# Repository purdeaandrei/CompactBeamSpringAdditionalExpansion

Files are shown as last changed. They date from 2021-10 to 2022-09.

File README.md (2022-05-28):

# Compact Beamspring controller.

This controller only supports new style card edge connectors only, and it requires the side
of the card edge connector to be cut off, and the pins be bent 90 degress.

This is a variant of the controller that also includes an additional expansion header, designed
especially for 3278 A02 / 3279 2C keyboards with a top panel, sporting additional leds and
non-capacitive push buttons.
See https://github.com/purdeaandrei/CompactBeamSpring/issues/1 for some details about these keyboards.

See [top_panel_modifications.md](top_panel_modifications.md) for instructions on how to connect this controller
to the top panel of your 3278 A02 / 3279 2C keyboard.

## Images

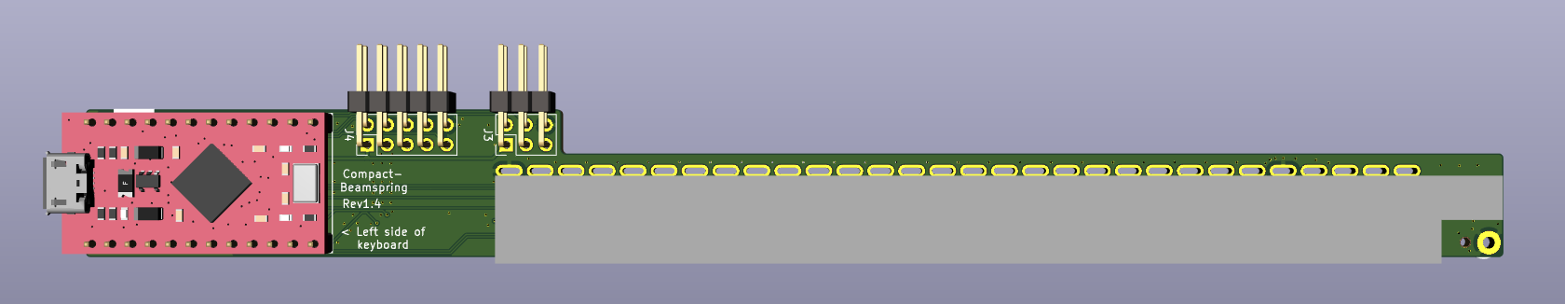
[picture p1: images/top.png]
Top of the controller board

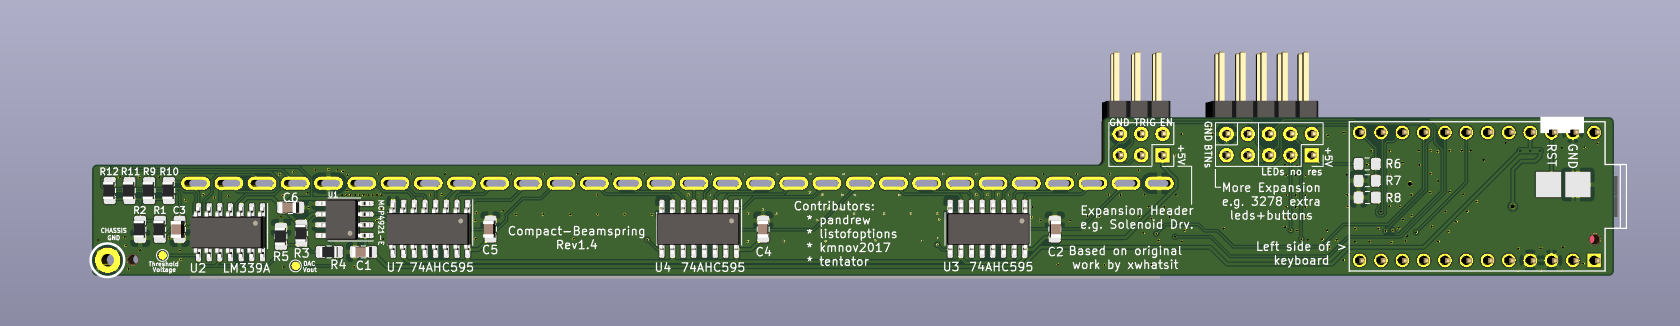
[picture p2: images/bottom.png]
Bottom of the controller board


## Other controllers in this family:
* https://github.com/purdeaandrei/CompactBeamSpring
* https://github.com/purdeaandrei/SMDModelFController
* https://github.com/purdeaandrei/SMDModelFController/tree/extra_columns
* https://github.com/purdeaandrei/SMD4704KishsaverClassModelFController
* https://github.com/listofoptions/TH-XWhatsIt

## Origins and license

This project is based on the Through-hole xwhatsit by listofoptions, which is un turn
based on the capsense controllers by XWhatsIt
(Tom Wong-Cornall). original liscencure holds, as well as CERN OSH
(compatible license).

original implementation of Tom Wong-Cornall's controller documented here

http://downloads.cornall.co/ibm-capsense-usb-web/ibm-capsense-usb.html

Working theory of operation is under the previous link.

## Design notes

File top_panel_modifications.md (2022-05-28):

# Top panel modifications

This document describes how to modify the top panel of the 3278 A02 / 3279 2C keyboard shown below:

## The top panel in its original state
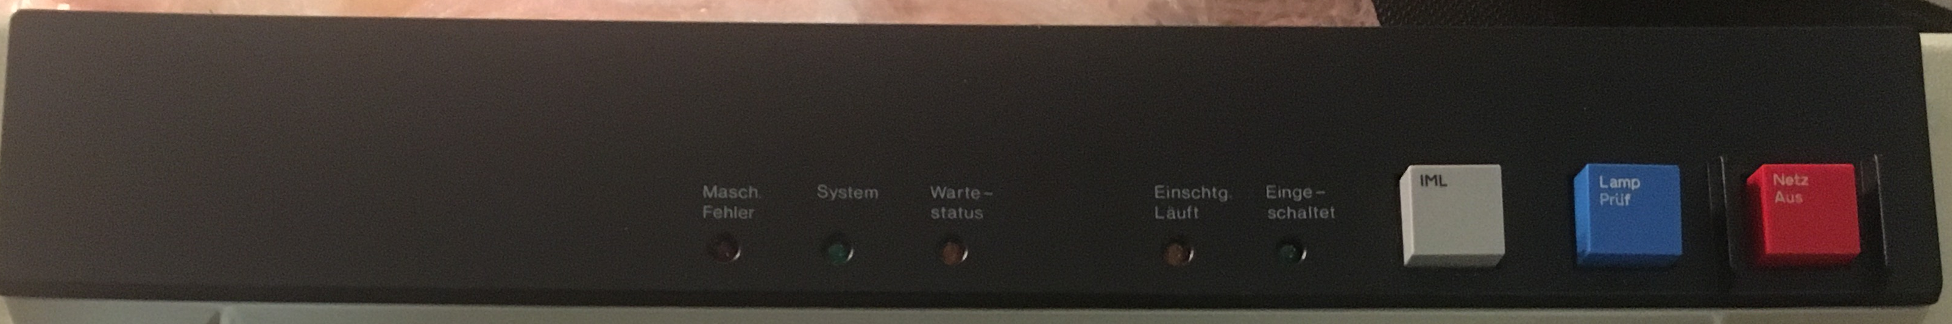
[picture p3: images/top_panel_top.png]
Top side of the top panel

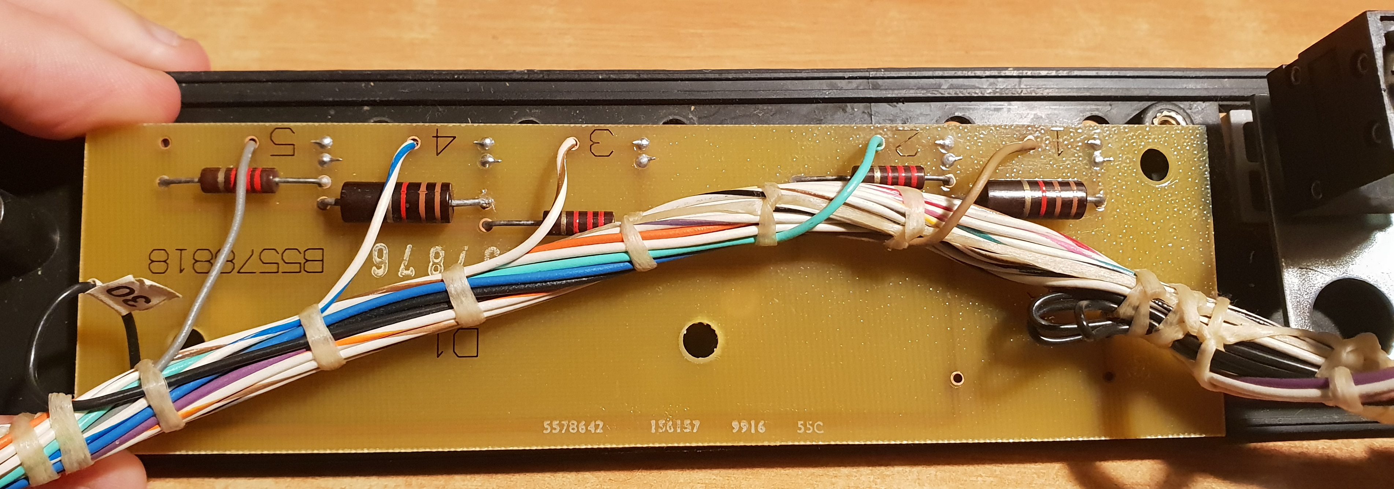
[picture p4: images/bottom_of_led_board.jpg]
Bottom side of the led pcb

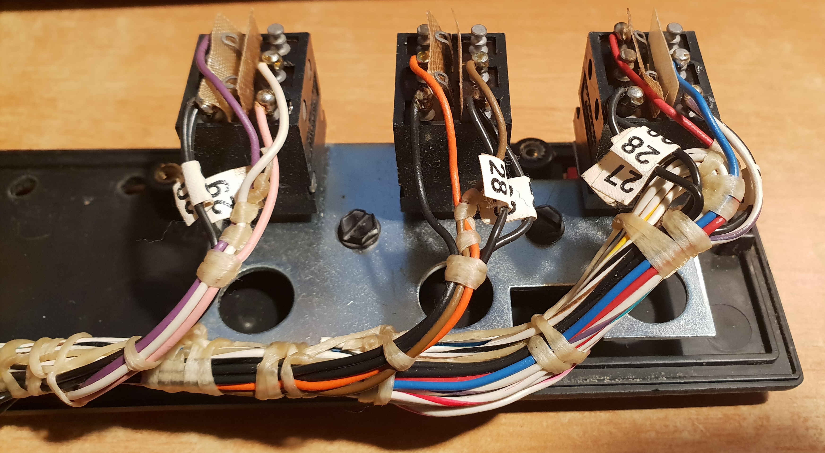
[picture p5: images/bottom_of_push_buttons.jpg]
Bottom side of the push buttons


Note: for more details about the original state of the board, please see [here](images/original_wire_harness_leds_and_buttons.pdf), and [here](images/bottom_of_push_buttons_annotated.jpg).

## After the modifications, the bottom side of the top panel looks like this:
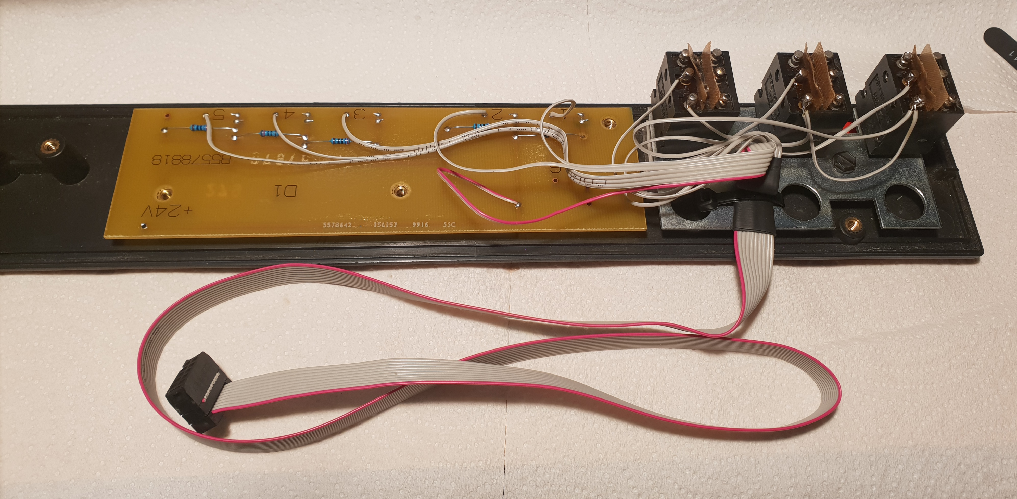
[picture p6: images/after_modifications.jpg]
After modifications


## Details

### Led Resistors

The original led board was designed to power the leds at 24 volts, so using the original current limiting resistors
at 5V, which is what our controller is running at, would make the leds too dim. In order to have the leds light at
a similar brightness as the original working condition of the keyboard, the resistors have to be replaced.

The following values have been calculated as recommended replacements. If you want to use these values
directly, please make sure that the board you're modifying had the same original resistor values as mentioned
in this table. Resistors are listed left-to-right:

| Led color | Index on PCB | Original resistor (@24V) | Recommended replacement (@5V) |
|---|---|---|---|
| Red | 5 | 2.2 kohm | 270 ohm |
| Green | 4 | 1.1 kohm | 120 ohm |
| Yellow | 3 | 2.2 kohm | 270 ohm |
| Yellow | 2 | 2.2 kohm | 270 ohm |
| Green | 1 | 1.1 kohm | 120 ohm |

Note: if you would like to see the raw spreadsheet we used to calculate the resistor values please see [here(.ods)](images/3278%20top%20panel%20led%20current%20limiting%20resistors.ods) or [here(.pdf)](images/3278%20top%20panel%20led%20current%20limiting%20resistors.pdf)

### New wire harness (using a ribbon cable)

#### Components

* 10-pin ribbon cable with 1.27mm pin pitch. We recommend using the single-color kind, that has only one edge wire with a different color. For example all-grey with pin "1" marked with red.
  * Example sources:
    * [tme](https://www.tme.eu/en/details/ds1057-10a282r/ribbon-cables-single-color/connfly/ds1057-10a282r-30-5/)
    * ebay, search "10 pin ribbon cable 1.27mm"
* 2x5-pin female IDC connector with 2.54mm pin pitch, and 1.27mm ribbon cable pitch:
  * Example sources:
    * [tme](https://www.tme.eu/en/details/ds1016-10masibb/idc-connectors/connfly/ds1016-10ma2bb/)
    * ebay, search "2x5 10 pin idc female"
* You also have the option to buy pre-crimped ribbon cables, and cut off one end, however you have less control over the length of the resulting cable harness.

Note: when crimping the IDC connector onto the ribbon cable, make sure to respect the pin 1 marker, which is usually a triangle/arrow showing which side pin 1 is on.

#### Wiring

| Ribbon pin index | Ribbon wire color | Controller net name | GPIO | Connect to |
|---|---|---|---|---|
| 1 | Red | +5VD | | "+24V" pin on led board, which is the **common anode** |
| 2 | Grey | LED1 | PF5  | "5" on PCB, The **left-most** led cathode |
| 3 | Grey | LED2 | PB4  | "4" on PCB, The second led cathode from the left |
| 4 | Grey | LED3 | PB5  | "3" on PCB |
| 5 | Grey | HEADER2_LED4 | PE6  | "2" on PCB |
| 6 | Grey | HEADER1_LED5 | PD7  | "1" on PCB, The **right-most** led cathode |
| 7 | Grey | BUTTON1 | PB6  | The **left-most** push buttons's middle-left terminal  |
| 8 | Grey | BUTTON2 | PB3  | The middle push buttons's middle-left terminal |
| 9 | Grey | BUTTON3 | PF4  | The **right-most** push buttons's middle-left terminal |
| 10 | Grey | GND | | The bottom-left pins of **all 3 push-buttons** |

Here is a futher illustrated image, explaining how to connecto the wires:

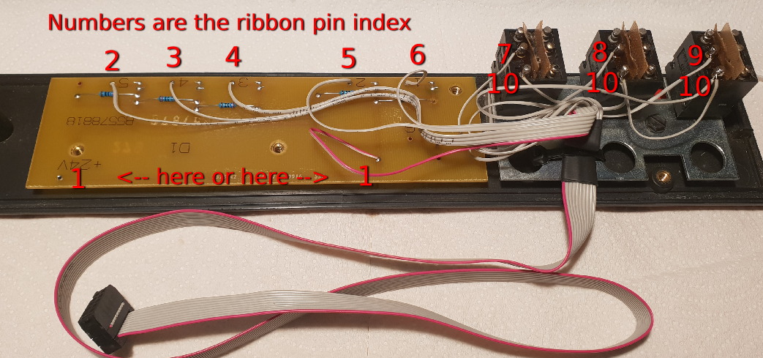
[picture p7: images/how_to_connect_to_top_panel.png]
How to connect


Here is an example of how to provide some strain relief to the ribbon cable using some heatshrink tubing, and a cable tie:

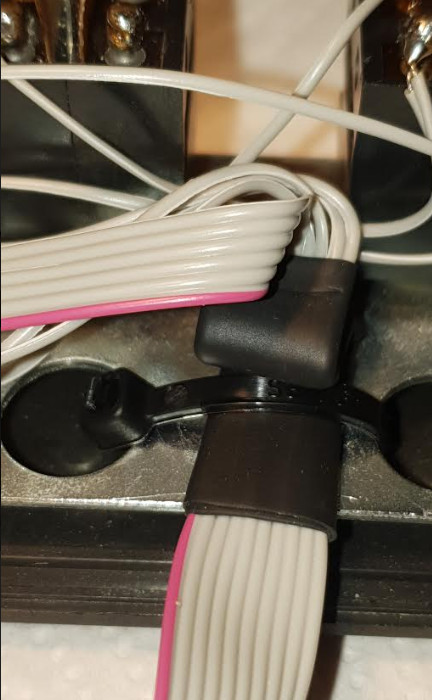
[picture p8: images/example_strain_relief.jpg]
Example strain relief


#### Connecting to the controller

Always make sure the pin "1" of the ribbon cable (the side marked with red) is lined up with pin "1" on controller.
Note: pin 1 on the controller is the only pad that is square, and it's also marked differently on the silkscreen.

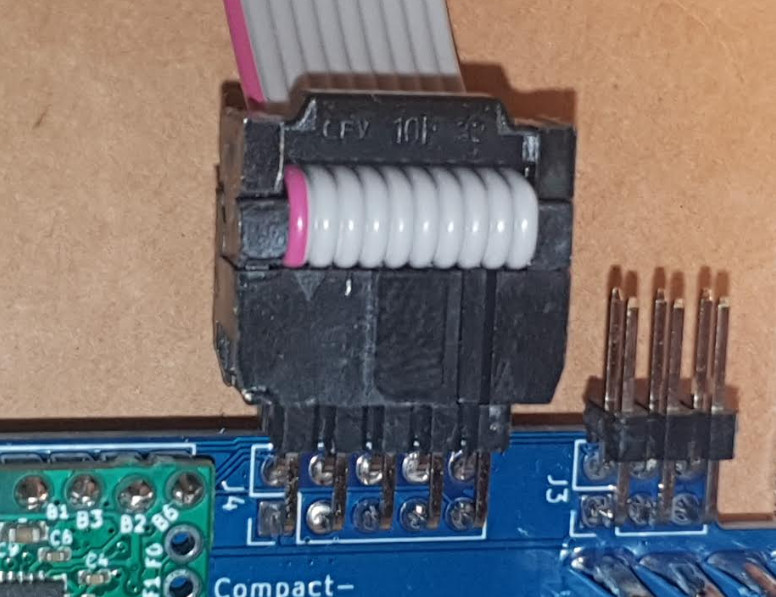
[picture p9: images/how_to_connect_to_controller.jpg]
How to connect


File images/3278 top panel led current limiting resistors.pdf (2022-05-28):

3278 A02 / 3279 2C keyboard top panel led behavour measured.

The original keyboard powered the led board at 24V.
The purpose of this table is to calculate the best replacement resistors to use at 5V, in order to closest approximate the original brightness of the leds.

Each led was powered, through its original current limiting resistor, at 23.9V with a lab power supply, and voltage drop and current were measured.

Right to Left: | Test voltage: | | 23.9 | V | | | Atmega VOL at measured current (V)
| Index on PCB | Current at 24V with original resistor | Original Resistance Measured | Resistance Color Code | Voltage on LED | -40degC | 25degC | 85degC | Total voltage available at 25degC | Voltage dropped by new resistor | New Resistor (ohms) | New resistor std value (ohms)
Green | 1 | 19.12 | mA | 1.122 | kohm | 1.1k | 2.19 | 0.55 | 0.68 | 0.9 | 4.32 | 2.13 | 111.4016736 | 120
Yellow | 2 | 9.4 | mA | 2.33 | kohm | 2.2k | 2.07 | 0.25 | 0.3 | 0.5 | 4.7 | 2.63 | 279.787234 | 270
Yellow | 3 | 9.17 | mA | 2.47 | kohm | 2.2k | 2.2 | 0.25 | 0.3 | 0.5 | 4.7 | 2.5 | 272.6281352 | 270
Green | 4 | 19.38 | mA | 1.116 | kohm | 1.1k | 2.07 | 0.55 | 0.68 | 0.9 | 4.32 | 2.25 | 116.0990712 | 120
Red | 5 | 9.48 | mA | 2.31 | kohm | 2.2k | 2.06 | 0.25 | 0.3 | 0.5 | 4.7 | 2.64 | 278.4810127 | 270

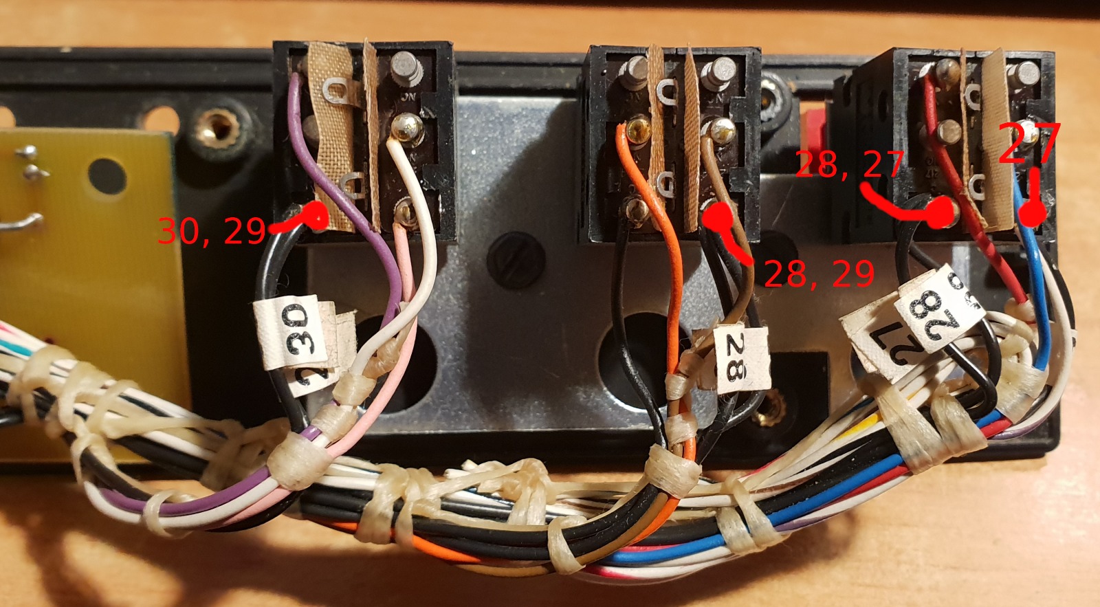
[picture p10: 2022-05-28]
images/bottom_of_push_buttons_annotated.jpg

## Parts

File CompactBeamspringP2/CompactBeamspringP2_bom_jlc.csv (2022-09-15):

Comment | Designator | Footprint | LCSC Part #
0U1 | C2,C6,C5,C3,C1,C4 | C_0805_2012Metric_Pad1.15x1.40mm_HandSolder | C49678
1K | R2 | R_0805_2012Metric_Pad1.15x1.40mm_HandSolder | C17513
20K | R4,R3 | R_0805_2012Metric_Pad1.15x1.40mm_HandSolder | C4328
4K7 | R5,R1 | R_0805_2012Metric_Pad1.15x1.40mm_HandSolder | C17673
100k 1% | R9,R10,R11,R12 | R_0805_2012Metric_Pad1.15x1.40mm_HandSolder | C149504
MCP4921-E | U1 | SOIC-8_3.9x4.9mm_P1.27mm | C43499
LM339A | U2 | SOIC-14_3.9x8.7mm_P1.27mm | C74559
74AHC595 | U3,U4,U7 | SOIC-16_3.9x9.9mm_P1.27mm | C5520

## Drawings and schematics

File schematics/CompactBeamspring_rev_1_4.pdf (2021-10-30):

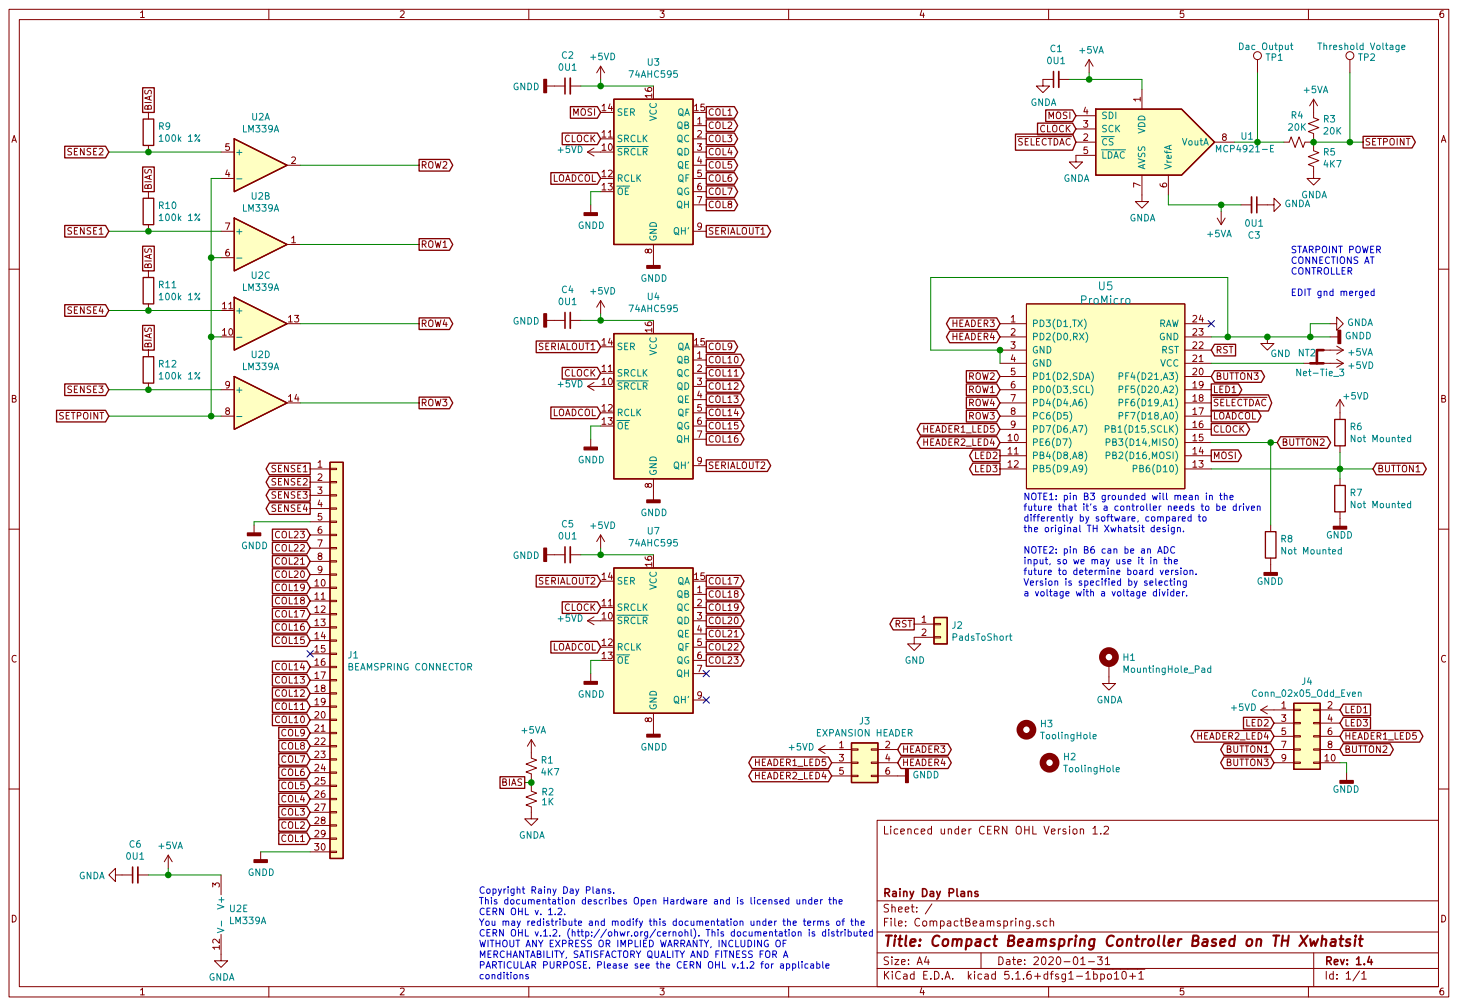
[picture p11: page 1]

future that it's a controller needs to be driven
differently by software, compared to
the original TH Xwhatsit design.

NOTE2: pin B6 can be an ADC
input, so we may use it in the
future to determine board version. Version is specified by selecting

a voltage with a voltage divider.

Licenced under CERN OHL Version 1.2

Copyright Rainy Day Plans.
This documentation describes Open Hardware and is licensed under the CERN OHL v. 1.2. You may redistribute and modify this documentation under the terms of the

File: CompactBeamspring.sch Sheet: / Rainy Day Plans

Id: 1/1 Title: Compact Beamspring Controller Based on TH Xwhatsit

CERN OHL v.1.2. (http://ohwr.org/cernohl). This documentation is distributed WITHOUT ANY EXPRESS OR IMPLIED WARRANTY, INCLUDING OF MERCHANTABILITY, SATISFACTORY QUALITY AND FITNESS FOR A

PARTICULAR PURPOSE. Please see the CERN OHL v.1.2 for applicable
conditions

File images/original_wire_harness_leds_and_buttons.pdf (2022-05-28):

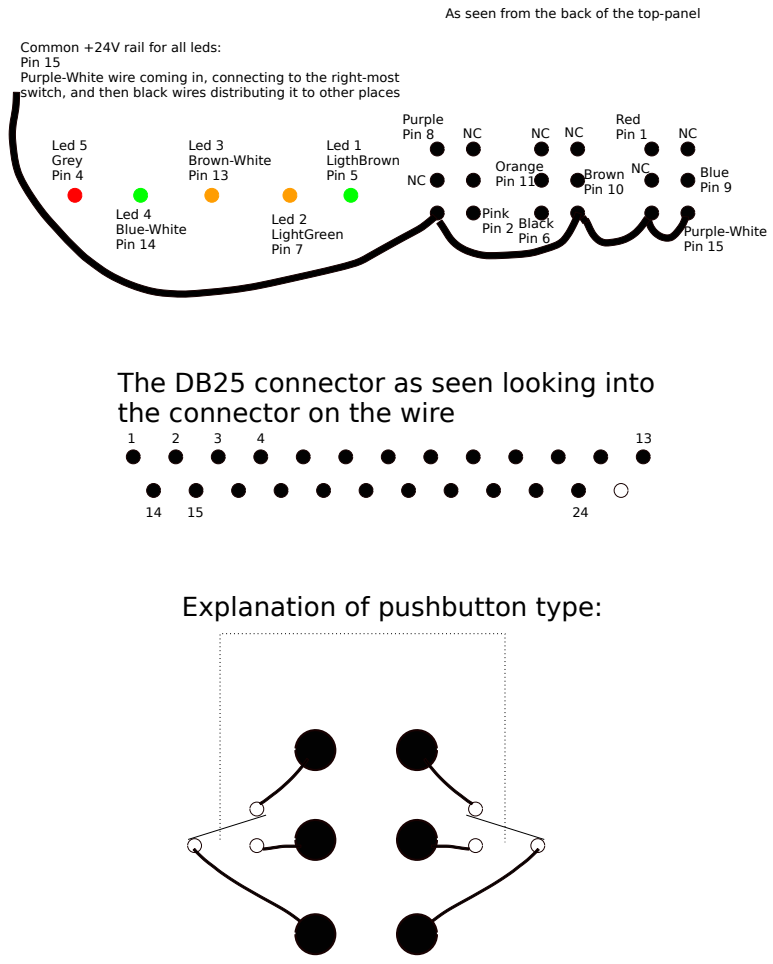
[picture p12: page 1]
Led 5 Grey Pin 4; Led 4 Blue-White Pin 14; Led 3 Brown-White Pin 13; Led 2 LightGreen Pin 7; Led 1 LigthBrown Pin 5; Purple-White Pin 15; Purple Pin 8; Blue Pin 9; Red Pin 1; Brown Pin 10; Orange Pin 11; Pink Pin 2; Black Pin 6

As seen from the back of the top-panel

Common +24V rail for all leds:
Pin 15
Purple-White wire coming in, connecting to the right-most
switch, and then black wires distributing it to other places

The DB25 connector as seen looking into
the connector on the wire

Explanation of pushbutton type:

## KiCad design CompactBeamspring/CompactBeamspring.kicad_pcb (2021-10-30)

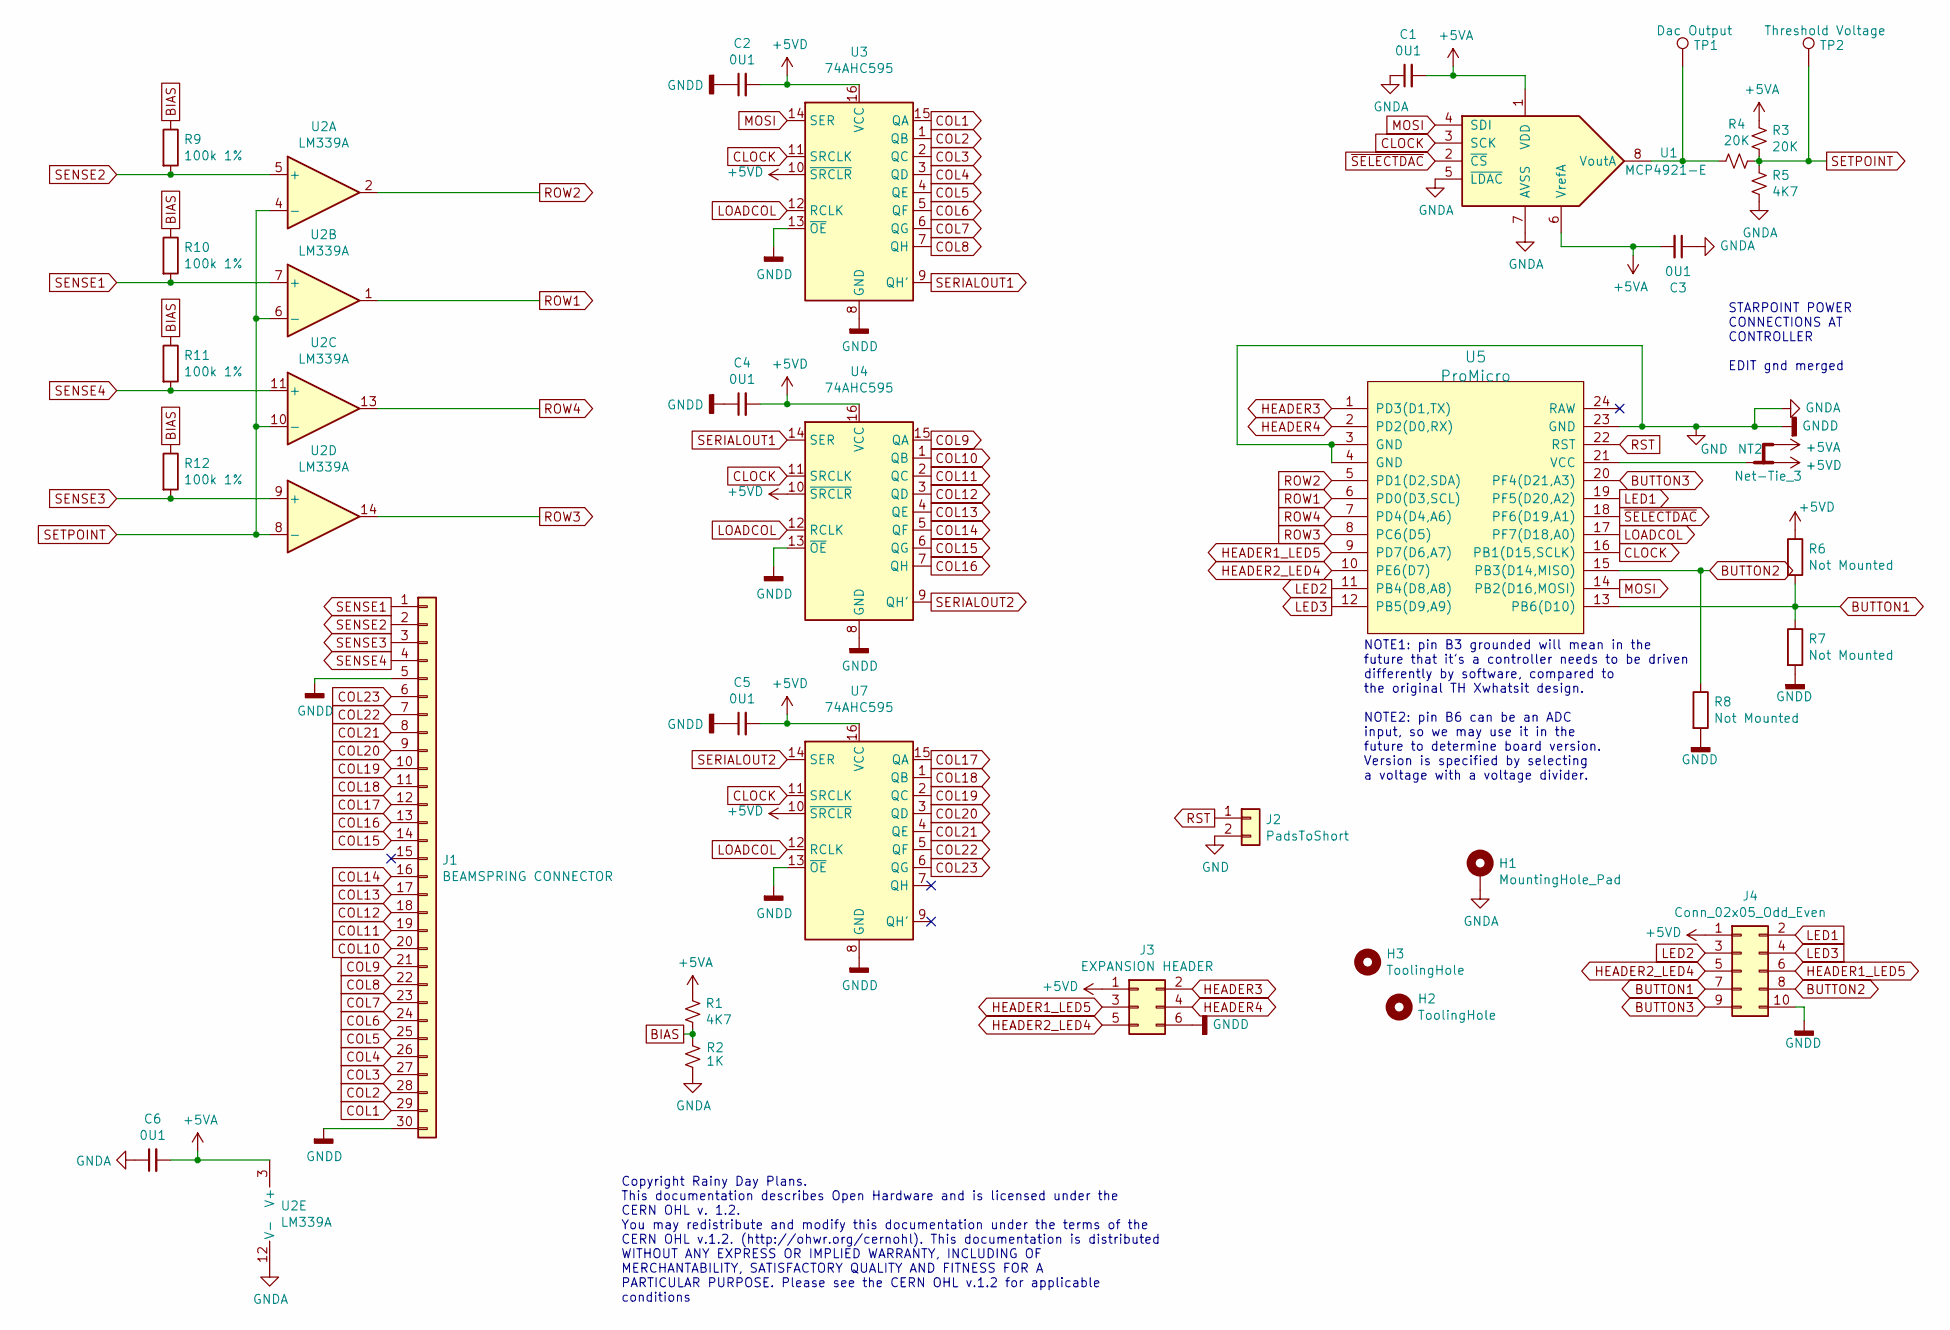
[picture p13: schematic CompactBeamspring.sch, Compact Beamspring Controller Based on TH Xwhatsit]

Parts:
C1, C2, C3, C4, C5, C6: 0U1; C_0805_2012Metric_Pad1.15x1.40mm_HandSolder; LCSC C49678
H1: MountingHole_Pad; ChassisGnd
H2, H3: ToolingHole; tooling_hole
J1: BEAMSPRING CONNECTOR; 30-pin-universal-beamspring-connector_v3_onlyflat
J2: PadsToShort
J3: EXPANSION HEADER; PinHeader_2x03_P2.54mm_Vertical
J4: Conn_02x05_Odd_Even; PinHeader_2x05_P2.54mm_Vertical
NT2: Net-Tie_3; NetTie-3_THT_Pad0.3mm
R1, R5: 4K7; R_0805_2012Metric_Pad1.15x1.40mm_HandSolder; LCSC C17673
R2: 1K; R_0805_2012Metric_Pad1.15x1.40mm_HandSolder; LCSC C17513
R3, R4: 20K; R_0805_2012Metric_Pad1.15x1.40mm_HandSolder; LCSC C4328
R6, R7, R8: Not Mounted; R_0805_2012Metric_Pad1.15x1.40mm_HandSolder
R9, R10, R11, R12: 100k 1%; R_0805_2012Metric_Pad1.15x1.40mm_HandSolder; LCSC C17407
TP1: Dac Output; TestPoint_Pad_D1.0mm
TP2: Threshold Voltage; TestPoint_Pad_D1.0mm
U1: MCP4921-E; SOIC-8_3.9x4.9mm_P1.27mm; LCSC C43499
U2: LM339A; SOIC-14_3.9x8.7mm_P1.27mm; LCSC C74559
U3, U4, U7: 74AHC595; SOIC-16_3.9x9.9mm_P1.27mm; LCSC C5520
U5: ProMicro

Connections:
+5VA: C1.2, C3.2, C6.2, NT2.3, R1.1, R3.2, U1.1 (VDD), U1.6 (VrefA), U2.3 (V+)
+5VD: C2.2, C4.2, C5.2, J3.1, J4.1, NT2.1, R6.1, U3.10 (~SRCLR), U3.16 (VCC), U4.10 (~SRCLR), U4.16 (VCC), U7.10 (~SRCLR), U7.16 (VCC)
BIAS: R1.2, R2.2, R9.1, R10.1, R11.1, R12.1
BUTTON1: J4.7, R6.2, R7.1, U5.13 (PB6(D10))
BUTTON2: J4.8, R8.1, U5.15 (PB3(D14,MISO))
BUTTON3: J4.9, U5.20 (PF4(D21,A3))
CLOCK: U1.3 (SCK), U3.11 (SRCLK), U4.11 (SRCLK), U5.16 (PB1(D15,SCLK)), U7.11 (SRCLK)
COL1: J1.29, U3.15 (QA)
COL2: J1.28, U3.1 (QB)
COL3: J1.27, U3.2 (QC)
COL4: J1.26, U3.3 (QD)
COL5: J1.25, U3.4 (QE)
COL6: J1.24, U3.5 (QF)
COL7: J1.23, U3.6 (QG)
COL8: J1.22, U3.7 (QH)
COL9: J1.21, U4.15 (QA)
COL10: J1.20, U4.1 (QB)
COL11: J1.19, U4.2 (QC)
COL12: J1.18, U4.3 (QD)
COL13: J1.17, U4.4 (QE)
COL14: J1.16, U4.5 (QF)
COL15: J1.14, U4.6 (QG)
COL16: J1.13, U4.7 (QH)
COL17: J1.12, U7.15 (QA)
COL18: J1.11, U7.1 (QB)
COL19: J1.10, U7.2 (QC)
COL20: J1.9, U7.3 (QD)
COL21: J1.8, U7.4 (QE)
COL22: J1.7, U7.5 (QF)
COL23: J1.6, U7.6 (QG)
GND: C1.1, C2.1, C3.1, C4.1, C5.1, C6.1, H1.1, J1.5, J1.30, J2.2, J3.6, J4.10, R2.1, R5.1, R7.2, R8.2, U1.5 (~LDAC~), U1.7 (AVSS), U2.12 (V-), U3.8 (GND), U3.13 (~OE), U4.8 (GND), U4.13 (~OE), U5.3 (GND), U5.4 (GND), U5.23 (GND), U7.8 (GND), U7.13 (~OE)
HEADER1_LED5: J3.3, J4.6, U5.9 (PD7(D6,A7))
HEADER2_LED4: J3.5, J4.5, U5.10 (PE6(D7))
HEADER3: J3.2, U5.1 (PD3(D1,TX))
HEADER4: J3.4, U5.2 (PD2(D0,RX))
LED1: J4.2, U5.19 (PF5(D20,A2))
LED2: J4.3, U5.11 (PB4(D8,A8))
LED3: J4.4, U5.12 (PB5(D9,A9))
LOADCOL: U3.12 (RCLK), U4.12 (RCLK), U5.17 (PF7(D18,A0)), U7.12 (RCLK)
MOSI: U1.4 (SDI), U3.14 (SER), U5.14 (PB2(D16,MOSI))
unnamed: NT2.2, U5.21 (VCC)
unnamed: R4.2, TP1.1, U1.8 (VoutA)
ROW1: U2.1, U5.6 (PD0(D3,SCL))
ROW2: U2.2, U5.5 (PD1(D2,SDA))
ROW3: U2.14, U5.8 (PC6(D5))
ROW4: U2.13, U5.7 (PD4(D4,A6))
RST: J2.1, U5.22 (RST)
SENSE1: J1.1, R10.2, U2.7 (+)
SENSE2: J1.2, R9.2, U2.5 (+)
SENSE3: J1.3, R12.2, U2.9 (+)
SENSE4: J1.4, R11.2, U2.11 (+)
SERIALOUT1: U3.9 (QH'), U4.14 (SER)
SERIALOUT2: U4.9 (QH'), U7.14 (SER)
SETPOINT: R3.1, R4.1, R5.2, TP2.1, U2.4 (-), U2.6 (-), U2.8 (-), U2.10 (-)
~SELECTDAC: U1.2 (~CS~), U5.18 (PF6(D19,A1))

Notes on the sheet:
Copyright Rainy Day Plans. This documentation describes Open Hardware and is licensed under the CERN OHL v. 1.2. You may redistribute and modify this documentation under the terms of the CERN OHL v.1.2. (http://ohwr.org/cernohl). This documentation is distributed WITHOUT ANY EXPRESS OR IMPLIED WARR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
NOTE1: pin B3 grounded will mean in the future that it's a controller needs to be driven differently by software, compared to the original TH Xwhatsit design. NOTE2: pin B6 can be an ADC input, so we may use it in the future to determine board version. Version is specified by selecting a voltage wi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
STARPOINT POWER CONNECTIONS AT CONTROLLER EDIT gnd merged

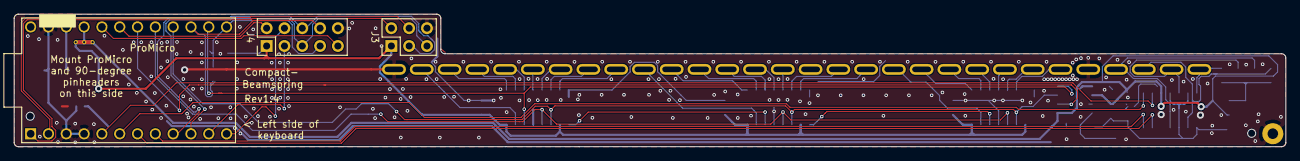
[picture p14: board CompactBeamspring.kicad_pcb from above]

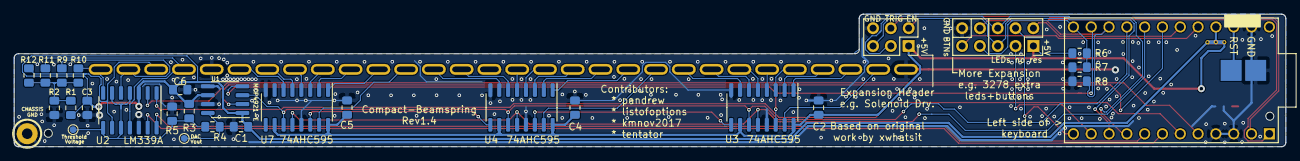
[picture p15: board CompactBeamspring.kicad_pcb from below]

Board: 2 copper layers, 181.3 x 18.9 mm, 34 parts (28 on the bottom side), 55 nets.

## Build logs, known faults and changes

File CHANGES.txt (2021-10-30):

January 31St, 2020:
    user: Listofoptions
        done:
            initial commit, completed main controller board and schematic
        todo:
            plugboard wiring and socket / connector positioning
            physical hardware testing
            firmware 
            firmware testing

Febuary 3rd, 2020
    user: Listofoptions
        done:
            moved setpoint decoupler cap to hopefully lower interferance with
            relatively high frequency output from the comparitors
            
            connector positioning for plugboard complete
            
            moved sense connector to allow better placement of corresponding
            socket on plugboards (sense traces needed more room on plugboards)
        todo:
            displaywriter plugboard wiring
            physical hardware testing
            firmware
            firmware testing
Febuary 4th, 2020
    user: listofoptions
        done:
            added ground strap points to plugboards, and positioned them to
            align with the ground strap on the main board
            
            displaywriter plugboard completely wired
            
            added cutouts in plugboards for expasion header wiring
        todo:
            maybe add more grounding straps to aid in mechanical strength
            (i intend to use metal standoffs to connect the plugboards and 
            main board)
            
            physical hardware testing
            firmware
            firmware testing
August 14th, 2020
    user: listofoptions
        done:
            complete smd rework 
        todo:
            fine tune the castelations
            add cutouts for throughhole components to pigybacking plugboards
            rewire and resize plugboards for max compatibility
            physical hardware testing
            firmware
            firmware testing

Unknown Date
    user: purdeandrei
        done:
            Renamed to Compact Beamspring Controller. First revision seen by the public is Rev. 1.3
            Trimmed down design to be specific to beamspring controllers
            Removed usage of resistor networks, now using individual resistors.
            Reverted some pinout changes to make it compatible to the original TH-Xwhatsit
            PCB layout re-done from scratch, to be as small as possible.
May 3, 2021
    user: purdeaandrei
        done:
            Updated Pro Micro schematic symbol, to correct pin names, and be more verbose.
            Added schematics in pdf form.

Oct 30, 2021
    user: purdeaandrei
        done:
            Removed datasheets
            Updated some licensing info
            Pro Micro 3D model: added pins
            Solenoid header, use 90-degree 3d model
            Added rendered images, tweaked readme

August 3, 2021
    user: purdeaandrei
        done:
            Revision 1.4
            Added extra expansion header, mainly for IBM 3278 with extra leds and buttons, board is now wider.
            Merged analog and digital grounds.
            This revision now only has the P2 panelisation.
            Added some more vias.

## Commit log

2021-10-30 Updated to rev. 1.4
    [CompactBeamspring.kicad_pcb, CompactBeamspring.sch, CompactBeamspringP1.kicad_pcb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]
2022-05-28 Update component rotations, to match new behaviour of JLCPCB on the bottom layer
    [CompactBeamspringP2_cpl_jlc.csv]
2022-05-28 Added document to describe top panel modifications
    [3278 top panel led current limiting resistors.ods]
2022-07-31 Updated shift register and 100k resistor LCSC part numbers
    [CompactBeamspring.sch, CompactBeamspringP2_bom_jlc.csv]
2022-07-31 fix rotations to match latest JLCPCB behaviour
    [CompactBeamspringP2_cpl_jlc.csv]
2022-09-15 Revert part of commit 'Updated 100k resistor and shift register LCSC part numbers' (the shift register BOM changes only)
    [CompactBeamspring.sch, CompactBeamspringP2_bom_jlc.csv]
